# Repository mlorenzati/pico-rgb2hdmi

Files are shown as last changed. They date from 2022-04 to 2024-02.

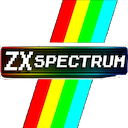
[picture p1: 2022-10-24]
tools/images/ZX-Spectrum.png

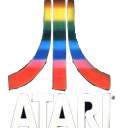
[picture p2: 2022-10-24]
tools/images/atari.png

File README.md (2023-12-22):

# pico-rgb2hdmi


Raspberry Pico as an RGB Scanner to HDMI Converter

## About the device
The device presents a simplistic approach of using a single generic purpose microcontroller to capture in real time RGB (CSYNC / HVSYNC) signals and to display it in an HDMI output without requiring FPGA chipsets of Single Boards computers with an HDMI diplay.
This system relies on the use of the PIO capabilities of the RP2040, to do dedicated processing of IO signals enabled with IRQ and DMA capabilites of the processor.

## Methodology
One processor is mostly dedicating to generate HDMI TMDS signals and the other to capture trigger captures and render on screen information among other functionalities.
PIO + DMA are used to dedicate the capture without requiring CPU intervention and to send the TMDS frames to the HDMI diplay.

# License - updated
The project full under the terms of the MIT license

# Collaboration
You are encouraged to build, develop and share, if you want to collaborate share PRs and github issues.

# Disclaimers
This solution (HW / FW /SW)  is provided as is without any express or implied warranties.

While every effort has been taken to ensure the solution will work as is, the authors & contributors assume no responsibility for errors or omissions, or for damages resulting from the use of the solution of the information contained herein.
There is no guarantee as to the suitability of said source code, executable scripts, circuits and other information, for any purpose whatsoever other than as a self-training aid.
I.E. If it blows your equipments, trashes your hard disc, wipes your backup, burns your building down or just plain don't work, IT ISN'T MY FAULT
I will not be held responsible for any damages or costs which might occur as a result of the usage of the beforementioned solution, USE IT AT YOUR OWN RISK

# Donations
You can allways collaborate to buy me coffees to focus on new cool features, this is my paypal.
[paypalme mlorenzati](https://www.paypal.com/paypalme/mlorenzati)

# PCB
You can build yourself the PCB out of the gerber in HW section, if you wan you can buy it in [pbcway pico-rgb2hdmi](https://www.pcbway.com/project/shareproject/pico_RGB_2_HDMI_3b12cb39.html)

# Setup
- Download the pico-sdk, pico-extras, and pico-playground repositories
- Define PICO_SDK_PATH in your ~/.bashrc• 
- Download the pico-sdk repository

# Security
Install sha3sum to hash the binary

## Mac
```
brew install md5sha1sum
```

## Local sha3sum usage for sha256
```
sha1sum <file>
echo -n "<device_salt><device_uid>" | sha1sum -b
```
## Tools
Tools were developed for sake of simplicity, focus is on firmware. 
It is required to install python3, pip and the following packages

```
pip install pyserial numpy pillow pyinstaller
```

## converting CSV captures from serial port to images
```
python3 csv2png.py image.csv
```
This generates as output image.png

## Using packtiles to generate include headers from images

./packtiles -s -f r1 char_c64_lineal.png font_c64.h

## Using packtiles to generate sprites
./packtiles -sdf rgab5515 -m  images/commodore.png cbm.h

## Running the python gui app
```
python .\rgb2hdmiGui.py
```

## Packaging the python app as a native app
```
pyinstaller -w -F rgb2hdmiGui.py
```

# Build
```
mkdir build
cd build
cmake .. -DCMAKE_BUILD_TYPE=Debug
```
Go to the specific folder and

`make -j4`

# Visual Studio Code integration
Install the extensions as explained in the  [Pico Getting started manual](https://datasheets.raspberrypi.org/pico/getting-started-with-pico.pdf)

Or just download [VScode](https://code.visualstudio.com/Download) and add the following extension

```
code --install-extension marus25.cortex-debug
code --install-extension ms-vscode.cmake-tools
code --install-extension ms-vscode.cpptools
```

# Debug
Install open ocd as explained in the [Pico Getting started manual section Installing OpenOCD](https://datasheets.raspberrypi.org/pico/getting-started-with-pico.pdf)

#Using Pico probe
On the same document check **Appendix A: Using Picoprobe**

Open deploy and run
```
openocd -f interface/picoprobe.cfg -f target/rp2040.cfg -c "program <specific elf file> verify reset exit"
```

# Read RP2040 to uf2
```
picotool save -a pico_rgb2hdmi_xyz.uf2
```

# Videos
pico RGB2HDMI Unified Firmware (https://youtu.be/40rTiWgZHxM)

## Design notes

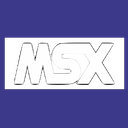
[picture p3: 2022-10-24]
tools/images/MSX.png

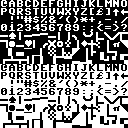
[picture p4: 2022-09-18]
tools/images/Font_64.png

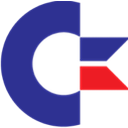
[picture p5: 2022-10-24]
tools/images/commodore.png

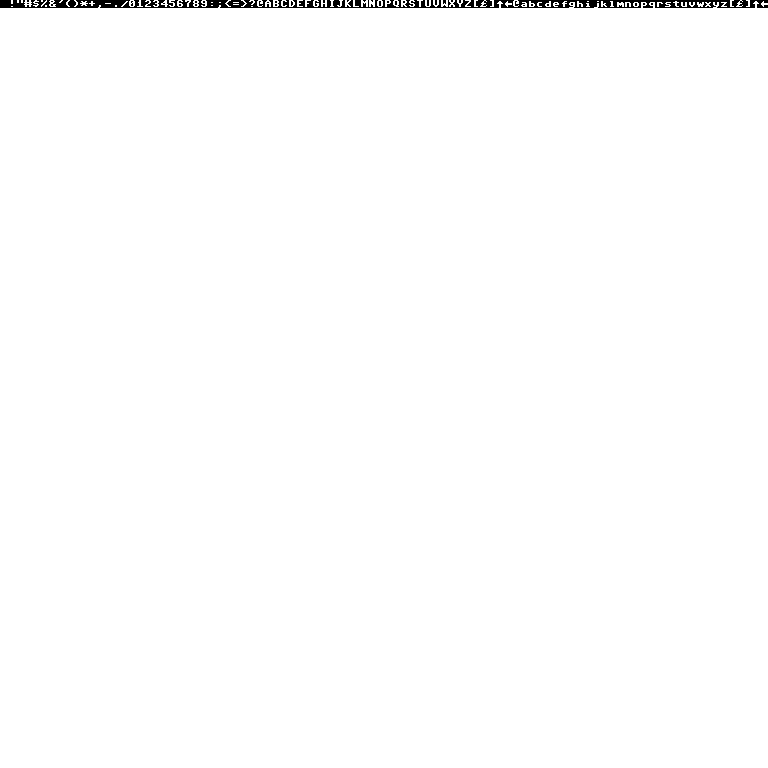
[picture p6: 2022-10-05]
tools/images/char_c64_lineal.png

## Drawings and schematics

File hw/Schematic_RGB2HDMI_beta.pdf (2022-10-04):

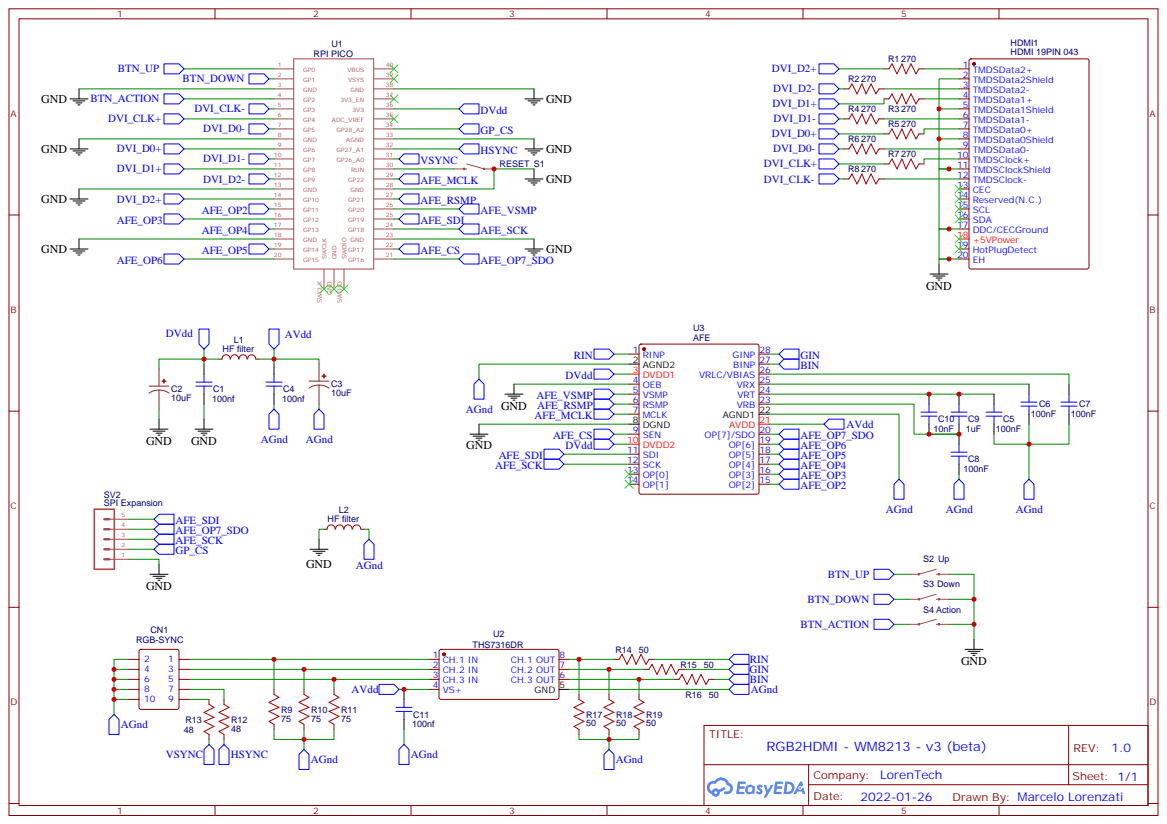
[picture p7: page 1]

Drawn By: Marcelo Lorenzati

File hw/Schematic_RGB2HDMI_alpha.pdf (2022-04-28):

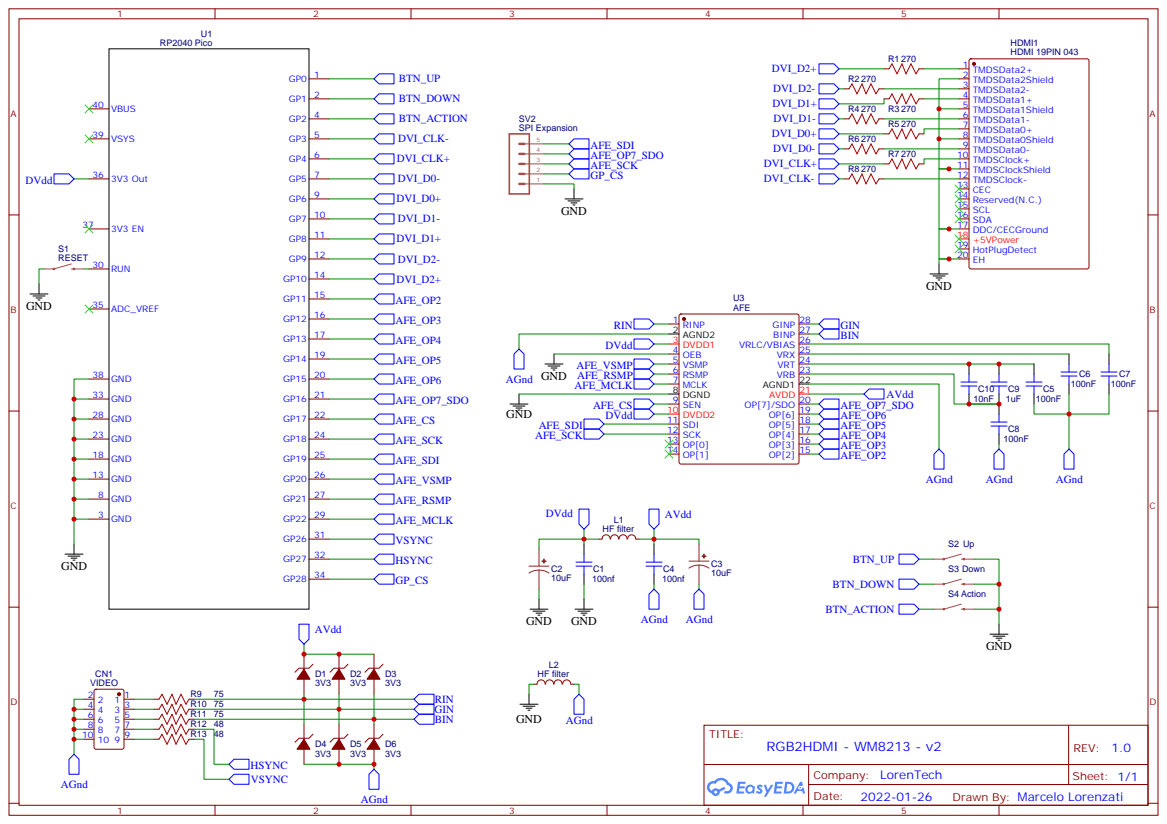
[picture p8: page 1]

Drawn By: Marcelo Lorenzati

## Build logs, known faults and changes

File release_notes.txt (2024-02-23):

Release Notes:
pico rgb2hdmi

An rpi pico microprocessed rgb 2 hdmi plus rgb 2 usb on the fly converter
-------------------------------------------------------------------------
Date: 2024/02/22
Version: 0.6.4
- Menu system for total control of gain, positive and negative offset, with RGB and unified options
-------------------------------------------------------------------------
Date: 2023/09/01
Version: 0.6.3
- Option to disable license validation on flash
-------------------------------------------------------------------------
Date: 2023/06/26
Version: 0.6.2
- Fixed integration test compilation/linker dependency to timer 
- Added all uf2 artifacts to CI Job zip file
-------------------------------------------------------------------------
Date: 2023/04/27
Version: 0.6.1
- Fix for unique horizontal timing, when doubling the value is adapted from stored value
- Added fine tune for pixel width, adds or substract in 1Khz steps the sample rate
-------------------------------------------------------------------------
Date: 2023/04/27
Version: 0.6.0
Major feature update: Unified Display mode (resolution and color depth for capture and display)
- Remove compile definitions for display mode
- Added logic to dinamically manage DVI display, stop, reconfigure and start
- Unified timings calculations
- Menu colors for 8 and 16 bits, when changing display mode, colors are defaulted
- DVI speed up with cached pre calculations!
- Callbacks are display mode dependant on runtime
- Improved AFE configs separating const config from variable configs

-------------------------------------------------------------------------
Date: 2023/04/22
Version: 0.5.2
- Scan lines support with menu and settings when using vertical line repeat
- Display config 4 has a SOG (sync on green) setup
- Fixed gain error that limited to 63
-------------------------------------------------------------------------
Date: 2023/04/21
Version: 0.5.1
- Fixed GUI/Graphics test due to latest changes
- Fixed storage dependency for multicore
-------------------------------------------------------------------------
Date: 2023/04/14
Version: 0.5.0
Major feature update: added settings persistence and menu integration
- Save settings and revert to factory
- Maintains license, and cover upgrade process from basic settings
- Menu system updated for 4 displays options
- gain, offset, alignment, pix width, auto shutdown and gui palette can be saved

-------------------------------------------------------------------------
Date: 2023/04/12
Version: 0.4.5
- Fix for capture changes (like pixel width) that affected the pio and made it stall

-------------------------------------------------------------------------
Date: 2023/02/28
Version: 0.4.4
- Improvement over capture: trigger fast front porch dma, then prepare capture dma (dough!)
- keyboard wake: on key pressed the shutdown screen timer is refreshen when there is no video, wakes the screen too

-------------------------------------------------------------------------
Date: 2023/02/28
Version: 0.4.3
- Implemented DVI start / stop
- Implemented configurable HDMI display auto shutdown on no signal
- Auto starts DVI on signal
- Added a level of submenus with config and display groups

-------------------------------------------------------------------------
Date: 2023/02/25
Version: 0.4.2
- Added missing enable USB button on diagnostic for Command line on serial

-------------------------------------------------------------------------
Date: 2022/12/08
Version: 0.4.1
- Support and menu connection of gain and offset control
- Sampling rate removed from config, is calculated based on video settings

-------------------------------------------------------------------------
Date: 2022/12/08
Version: 0.4.0
- Included menu support based on an event based GUI
    - 8 object in left button groups
    - 8 objects in main view
    - show hide overlay with buttons
    - mapping of keys with event types
    - navigation on navigable object improvement
    - Added about, palette, save & reboot, diagnostics and alignment menues
        - Palette menu changes active colors
    - Factory option
    - Gain & offset, automatic option
    - license show and start image
    - alignment control connection to ui with pixel width
    - diagnostics shows sync type
- group unsubscribe improvement
- group loop callback tool with break condition and count of results
- focus change fix
- color api for RGB in different modes
- event fix to support multiple subscribers and destination with diferent actions
- event non propagation fix
- scanner provides number of hsync lines
- scanner sync type detection and show on screen
- scanner and afe can restart capture
-------------------------------------------------------------------------
Date: 2022/11/13
Version: 0.3.4
- Initial CSYNC support

-------------------------------------------------------------------------
Date: 2022/10/14
Version: 0.3.3
- Storage fix: 
  On new devices without license, the device went to watchdog reset
  
-------------------------------------------------------------------------
Date: 2022/10/04
Version: 0.3.2
- Completed UI Python App with autodetect, move screen buttons, capture
  and device identification
- GUI lib(not integrated to device)
  buttons, sliders, labels, spinbox and groups (shared and not shared)
  event management and propagation
  focus management
- Tiles and fonts tool
- Beta HW consolidation support
- Security: license validation fixes
- Storage: Usage of storage with a subsequent reboot
- Commands: reboot
- Added purchase mode fw with VYSNC/HSYNC info at the bottom of the screen

-------------------------------------------------------------------------
Date: 2022/08/09
Version: 0.3.1
- Image capture supports, 8 and 16 bits modes
- Added mode command to report current resolution and color density

-------------------------------------------------------------------------
Date: 2022/08/08
Version: 0.3.0
- Completed 640x240 8 bits RGB332 mode and 320x240 16 bits RGB 565 mode
on HMDI rendering and ADC capture compressing

-------------------------------------------------------------------------
Date: 2022/06/17
Version: 0.2.1
- Initial release of the rgb2hdmi
    - 320x240 @ 16 bits per pixel
    - Basic buttons functionality usage (move screen), supports on key up
      key down, key timeout
    - Secure key unique identification
    - Video overlay
    - Command line interface through USB (must be enabled from buttons)
        -RGB to USB Image capture
        -move image
    - Graphics drawing capabilities, initial menu system

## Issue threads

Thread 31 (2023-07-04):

Undefined reference during build

charlysan, 2023-07-04:
When trying to link `integrationTest.elf` I get an `undefined reference to video_overlay_scanline_prepare` error. Full log dump below:

```
/home/dev/build # cmake .. -DCMAKE_BUILD_TYPE=Debug && make
PICO_SDK_PATH is /usr/share/pico_sdk
PICO platform is rp2040.
Build type is Debug
Using regular optimized debug build (set PICO_DEOPTIMIZED_DEBUG=1 to de-optimize)
PICO target board is pico.
Using board configuration from /usr/share/pico_sdk/src/boards/include/boards/pico.h
TinyUSB available at /usr/share/pico_sdk/lib/tinyusb/src/portable/raspberrypi/rp2040; enabling build support for USB.
Compiling TinyUSB with CFG_TUSB_DEBUG=1
BTstack available at /usr/share/pico_sdk/lib/btstack
cyw43-driver available at /usr/share/pico_sdk/lib/cyw43-driver
Pico W Bluetooth build support available.
lwIP available at /usr/share/pico_sdk/lib/lwip
mbedtls available at /usr/share/pico_sdk/lib/mbedtls
-- Configuring done
-- Generating done
-- Build files have been written to: /home/dev/build
Scanning dependencies of target bs2_default
[  0%] Built target bs2_default
[  0%] Performing build step for 'PioasmBuild'
[100%] Built target pioasm
[  0%] No install step for 'PioasmBuild'
[  1%] Completed 'PioasmBuild'
[  1%] Built target PioasmBuild
[  1%] Built target rgbScan_wm8213Afe_pio_h
[  2%] Built target bs2_default_padded_checksummed_asm
Scanning dependencies of target rgbScanTest
Consolidate compiler generated dependencies of target rgbScanTest
[ 11%] Built target rgbScanTest
[ 11%] Built target libdvi_tmds_encode_1bpp_pio_h
[ 11%] Built target libdvi_dvi_serialiser_pio_h
Scanning dependencies of target hdmiTest
Consolidate compiler generated dependencies of target hdmiTest
[ 20%] Built target hdmiTest
Scanning dependencies of target afeTest
Consolidate compiler generated dependencies of target afeTest
[ 29%] Built target afeTest
Scanning dependencies of target keyboardTest
Consolidate compiler generated dependencies of target keyboardTest
[ 37%] Built target keyboardTest
Scanning dependencies of target storageTest
Consolidate compiler generated dependencies of target storageTest
[ 45%] Built target storageTest
[ 45%] Performing build step for 'ELF2UF2Build'
[100%] Built target elf2uf2
[ 45%] No install step for 'ELF2UF2Build'
[ 45%] Completed 'ELF2UF2Build'
[ 45%] Built target ELF2UF2Build
Scanning dependencies of target securityTest
Consolidate compiler generated dependencies of target securityTest
[ 53%] Built target securityTest
Scanning dependencies of target graphicsTest
Consolidate compiler generated dependencies of target graphicsTest
[ 62%] Built target graphicsTest
Scanning dependencies of target spriteTest
Consolidate compiler generated dependencies of target spriteTest
[ 72%] Built target spriteTest
Scanning dependencies of target guiTest
Consolidate compiler generated dependencies of target guiTest
[ 81%] Built target guiTest
Scanning dependencies of target integrationTest
Consolidate compiler generated dependencies of target integrationTest
[ 81%] Linking CXX executable integrationTest.elf
/usr/lib/gcc/arm-none-eabi/12.2.0/../../../../arm-none-eabi/bin/ld: CMakeFiles/integrationTest.dir/integrationTest.c.obj: in function `scanLineTriggered_8':
/home/dev/test/integrationTest/integrationTest.c:117: undefined reference to `video_overlay_scanline_prepare'
/usr/lib/gcc/arm-none-eabi/12.2.0/../../../../arm-none-eabi/bin/ld: CMakeFiles/integrationTest.dir/integrationTest.c.obj: in function `scanLineTriggered_16':
/home/dev/test/integrationTest/integrationTest.c:128: undefined reference to `video_overlay_scanline_prepare'
collect2: error: ld returned 1 exit status
make[2]: *** [test/integrationTest/CMakeFiles/integrationTest.dir/build.make:1638: test/integrationTest/integrationTest.elf] Error 1
make[1]: *** [CMakeFiles/Makefile2:2676: test/integrationTest/CMakeFiles/integrationTest.dir/all] Error 2
make: *** [Makefile:91: all] Error 2
```

I've checked the imports and `CMakeLists.txt` file, but everything looks OK.

Any clues on what I might be missing here?

Thanks!

mlorenzati, 2023-07-07:
Hi, long week, I did a clean CMAKE and make of the solution without issues.
from the root project I just
```
mkdir build && cd build && cmake .. &
make -j4
```
This compiled all without issues, just remember to set **PICO_SDK_PATH**\

Attached [logs.txt](https://github.com/mlorenzati/pico-rgb2hdmi/files/11986247/logs.txt)

Additionally setting the vscode environment it automatically set ups and builds everything

mlorenzati, 2023-07-07:
**video_overlay_scanline_prepare** is an inline method part of the overlay.h used only in the integration test.
CMakelist of integration test add overlay as a submodule, so it should work

charlysan, 2023-07-08:
Thanks for double checking that. It looks like I had some issue in my `build` directory. After I removed the folder and re builded everything from scratch again, I got no errors.

I'm closing this issue.

Closed 2023-07-08.

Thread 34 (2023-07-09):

MDA/Hercules Support

charlysan, 2023-07-09:
## Introduction

The purpose of this issue is to start a discussion about MDA/Hercules implementation.

## Requirements & specs

### Features and DB9 Pinout

Feature / DB9 Pin Number | IBM MDA | Hercules Graphics Card (HGC)
-- | -- | --
Text Mode | 80x25 characters (720x350 pixels) | 80x25 characters (720x350 pixels)
Graphics Mode | None | 720x348 pixels
Vertical Sync Frequency | 50 Hz | 50 Hz
Horizontal Sync Frequency | ~18.432 kHz | ~18.432 kHz
Signal Type | TTL Digital | TTL Digital
Pin 1 | Ground | Ground
Pin 2 | Ground | Ground
Pin 3 | Not connected | Not connected
Pin 4 | Not connected | Not connected
Pin 5 | Not connected | Not connected
Pin 6 | Intensity | Intensity
Pin 7 | Video | Video
Pin 8 | Horizontal Sync | Horizontal Sync
Pin 9 | Vertical Sync | Vertical Sync

<br class="Apple-interchange-newline">

### Intensity for Graphics Mode

Video | Intensity | Resulting 'colour'
-- | -- | --
0 | 0 | Black
0 | 1 | Dim
1 | 0 | Normal
1 | 1 | Bright

## Implementation

### Hardware

We could connect `Video` to `Rin`, and `Intensity` to `Gin` for example.

### Software

TBD

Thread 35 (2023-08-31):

CSYNC only will it work

shift838, 2023-08-31:
I have an old computer that has CSYNC, Red, Green, Blue and ground.

Will this work for a system that only has a CSYNC line?

mlorenzati, 2023-08-31:
Hi @shift838, short answer is yes, since the code is prepared to use HSYNC line to manage CSYNC when HSYNC is grounded.
The double click is that not all CSYNCs are the same, example wise I know it works with SEGA and AMIGA CSYNC, but Sinclair + uses inverter polarity for vertical inside the CSYNC.
The next step is to test it, and if it does not work we need to add a config option to invert VSYNC polarity triggering inside CSYNC.

shift838, 2023-09-01:
Is the latest gerbers the Beta3?

mlorenzati, 2023-09-02:
Latest PCB is on PCB Way
https://www.pcbway.com/project/shareproject/pico_RGB_2_HDMI_3b12cb39.html

I did not check the gerbers on github, that was other collaborator work

El vie, 1 sept 2023 a la(s) 18:37, shift838 ***@***.***)
escribió:

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

shift838, 2023-09-02:
Also it seems the wm8213 IC it is designed for is obsolete and so is the alternate WM8199.  Is there another IC that can be used on this board to replace it?

mlorenzati, 2023-09-02:
wm8199 is not yet a replacement there are some fundamental changes that
renders it invalid.
We need another AFE family

El sáb, 2 sept 2023, 0:19, shift838 ***@***.***> escribió:

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

mwedmark, 2023-10-31:
AD9826 seem to be very similar, still available pretty cheap but also "on the way out". Maybe worth trying out?

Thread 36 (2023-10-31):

Amiga DB23 To Beta3 Pin Header Mapping

mrgo0se, 2023-10-31:
Hi,

Is there an existing schematic/diagram anywhere showing the exact pin mapping between Amiga DB23 and the Beta3 PCB pin header signals, including appropriate grounds?

I am fairly confident that I have this wired correctly and get display/diagnostic menu on screen but only alternating black screen and garbled video signal output.

If you could post a mapping in the repo for wiring using CSYNC and alternatively HSYNC/VSYNC via the DB23 that would be great.

I'm also using the WM8214 AFE rather than the WM8213 if that makes any difference?

Cheers.

mlorenzati, 2023-10-31:
The picoRGB2HDMI is generalistic to use any retrocomputer with RGB or RGBi output (prior converting signal) that's why I do not add a circuit to the DB23 since its just pin to pin connection.
The board can use either CSYNC or HSYNC+VSYNC.
For the first one, leave board HSYNC Grounded and connect Amiga CSYNC to the board HSYNC.
Check here the pinout of Amiga https://inanis.net/amiga-500-to-amiga-1084-rgb-cable/
You can use one or the three ground amiga pin 16,17,18

Regarding WM8214 is compatible with WM8213 but faster, I saw that it might have a slightless timing difference that could shift colors. For sake of simplicity I'm about to push in this days a feature to manage gain/offset per RGB color.

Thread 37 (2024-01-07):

Firmware

thbreidenbach, 2024-01-07:
Hey, could you elaborate on the firmware release? The Binaries include several test u2f but I'm asking myself which is the exact firmware.
I just finished my build an hopefully it'll work.

mlorenzati, 2024-01-07:
Sure, there package has different test for the submodules, the one you want for RGB2HDMI is the integrationtest.uf2
Please start validating HDMI works (check the Resistor array is are not tied to each other or to ground), then check AFE.
If youc can validate with microscope the pins on the AFE and clean througfully solder flux since it affects the capture.

thbreidenbach, 2024-01-07:
Great, Thank! I upladed the integrationtest firmware and can successfully see the menu. Colors are washed out greatly which might be an issue with the used WM8214. Will start working on a db23 adapter and test on!!
Maybe you could collect the different sources of information (PCBWay, Google, etc.) here? I will assemble information for a1k.org and will give some assembled boards to testers there. Is there something to keep in mind regarding the WM8214 whilest troubleshooting?

mlorenzati, 2024-01-08:
I do need to complete what I started in https://github.com/mlorenzati/pico-rgb2hdmi/tree/gain_offset_options to allow offset and gain per RGB to manage the color differences due to timing between WM8213 and WM8214.
Also could be possible to tweak the timing on the pio capture program but that would be an overkill IMO.
If colors are shifted that's the wm8412 timing, if washed is more related to flux messing with an unwanted rc profile

thbreidenbach, 2024-01-11:
Hi, I get really bad sync and colors are way off which will be an issue of the wm8214. At first the picture is extremely dim ´. With gain and offset this can be partially solved but blue seems to be mostly missing. Would it be possible to output a dedicated test image on the host computer and let the pi calculate offset and gain per rgb?

mlorenzati, 2024-01-11:
Bad sync can be multiple things, please check videos on yt about how it looks like as for today, since video has some glitches that has to be managed on firmware but not extreme.
To validate you have a clean WM8214, (as I said clean with iso and toothbrush and clean with hot air on 200-240 degrees.

Finally, set video capture on 320x240 to  see how it looks, if better you have pending dirt.
I still need to complete manual per RGB gain and offset, no time to complete it yet.

ottifant011, 2024-01-30:
I have built myself a Pico RGB2HDMI.
How can I programme it under windows? Is there a manual for beginners?

thbreidenbach, 2024-01-30:
Usually one just connects the RPi Pico to the windows computer and drags the fw file in the newly added drive (which represents the pi) which firmware you need can be seen in this thread. (integrationtest.uf2)
Which Chip do you use? WM8213 or WM8214?

ottifant011, 2024-01-30:
hm i have already done that but nothing is happening, no image output no flashing led nothing.
I only got the WM8214

ottifant011, 2024-01-30:
if i de-energise the pico it seems to be empty again u2f file no longer there

ottifant011, 2024-01-30:
> @ottifant011, können Sie zunächst einmal ausprobieren `hdmiTest.uf2`. Das sollte einiges über den HDMI-Anschluss senden. Und denken Sie daran, dass sich der Pico im Massenspeichermodus befinden MUSS, um eine UF2-Datei darauf übertragen zu können. Halten Sie dazu die BOOTSEL-Taste gedrückt und schließen Sie dann den Pico an. Lassen Sie dann die BOOTSEL-Taste los.

das hab ich schon probiert das geht leider auch nichts bzw. kein HDMI Signal

ottifant011, 2024-01-30:
what i don't understand it is immediately recognised as a drive without me having to press a button

thbreidenbach, 2024-01-30:
Why wouldn’t it? That’s how it’s built.

mlorenzati, 2024-01-30:
@ottifant011, to burn the firmware into the device
- press RESET
- press BOOT
- release RESET
That should show the pen drive option on the computer

Start with the simple HDMI demo, test it in monitors with DVI back compatibility, TVs is more likely not to work with that firm.

HDMI support has to be integrated from what I built in https://github.com/mlorenzati/PicoDVI

ottifant011, 2024-01-31:
i just can't get a picture output, a monitor says outside the working area

charlysan, 2024-01-31:
@ottifant011, have you tried using a different monitor? My monitor experiences issues at certain resolutions, however, `hdmiTest.uf2` has always worked. What about your Pico? Have you checked to ensure it's working well?

charlysan, 2024-01-31:
I've just checked using `hdmiTest.uf2` from `pico-rgb2hdmi-0.6.3.zip` and it works as expected. I followed the [instructions](https://github.com/mlorenzati/pico-rgb2hdmi/issues/37#issuecomment-1917983604) from Marcelo.

ottifant011, 2024-01-31:
tomorrow i will build a new one piece by piece, for HDMI test picture you don't need an input circuit with ic's.
I'm building the Beta3 but that shouldn't matter, maybe the chinese have delivered with it.
Do all HDMI sockets have the same pinout? not that's where the fault lies

ottifant011, 2024-02-01:
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

I did it exactly the same way and no test image appears even when rebuilding

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

charlysan, 2024-02-01:
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

@ottifant011, I recommend opening a new issue titled 'No HDMI Output' for a detailed discussion on this problem, since the current thread is specifically for clarifying aspects of the firmware release.

And considering that the main question in this discussion has been resolved, I am now closing this issue.

cc: @mlorenzati

Closed 2024-02-01.

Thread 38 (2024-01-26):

WM8231? Other ICs?

King-Icewind, 2024-01-26:
Hello,

As you know, the WM2813 is now obsolete. What are your thoughts on using the WM8231? It is an active part for now.

Any other possible ICs to use? Could an STM32F11 be used in lieu of an AFE?

thanks!

mlorenzati, 2024-01-26:
On the first question, I have to see in detail but on a high level view,
there are significant differences. Just see WM8199, is pin compatible and
it has hw and peripherals differences.
I'm analysing the LM98714 which is 45Msps 3 channels afe and most
importantly cost effective.

Regarding the MCU, is heavy using the PIO interface that releases a lot of
cpu usage and has great interconnection to DMA/IRQ.

El vie, 26 ene 2024 a la(s) 7:24 p.m., Keys of Kings (
***@***.***) escribió:

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

King-Icewind, 2024-01-26:
> On the first question, I have to see in detail but on a high level view, there are significant differences. Just see WM8199, is pin compatible and it has hw and peripherals differences. I'm analysing the LM98714 which is 45Msps 3 channels afe and most importantly cost effective. Regarding the MCU, is heavy using the PIO interface that releases a lot of cpu usage and has great interconnection to DMA/IRQ. El vie, 26 ene 2024 a la(s) 7:24 p.m., Keys of Kings ( ***@***.***) escribió:
> […](#)
> Hello, As you know, the WM2813 is now obsolete. What are your thoughts on using the WM8231? It is an active part for now. Any other possible ICs to use? Could an STM32F11 be used in lieu of an AFE? thanks! — Reply to this email directly, view it on GitHub <#38>, or unsubscribe <https://github.com/notifications/unsubscribe-auth/ABJGQOZWGVMSHFNZOOKS4Z3YQQULNAVCNFSM6AAAAABCMZW772VHI2DSMVQWIX3LMV43ASLTON2WKOZSGEYDEOJYHA2TKOA> . You are receiving this because you are subscribed to this thread.Message ID: ***@***.***>

Thank you for the reply. Unfortunately, the WM8199 is end of life. I’m not worried about pin compatibility as my application is custom. Interested in the LM98714. Thanks for all the great work.

mlorenzati, 2024-02-25:
I'm placing my last bits into this version (HDMI + audio + stabilization) and I'll move to the R&D on LM98714, stay tuned!

mlorenzati, 2024-04-04:
Yes, it works perfectly and has higher sampling rate, if the colors get shifted due to timing differences, the latest version supports gain/offset setup per individual RGB

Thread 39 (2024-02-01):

No HDMI output

ottifant011, 2024-02-01:
@charlysan sorry for spamming the firmware topic, I thought I did something wrong when programming.
So I have a fully built card and a card half built and just get no picture output, it is not yet recognized that an HDMI is active.
I have the firmware HDMItest on it

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

charlysan, 2024-02-01:
No worries @ottifant011. I would do the following tests:

1. Check with different HDMI cable
2. Check with different monitor
3. Visually check HDMI connector (pins soldered to pcb pads)

ottifant011, 2024-02-01:
Thanks, tried several HDMI cables, only tested 2 monitors so far and used firmware from github. Hdmi socket optically checked no short circuits visible also measured the resistors to see if there are any short circuits.
are there HDMI sockets with different pinouts? i had some lying around and used these too.
What kind of monitors do you have? could you look in your company to see if you can find one?

mlorenzati, 2024-02-25:
If it is a monitor, it will work, on HDMI monitor is not that easy.
I have a Samsung S20B300B, a DELL U2415, an HP 20 inches I cannot see the model and a chinese TV/monitor.
If you want to test HDMI, compile and use the HDMI example (with audio) on https://github.com/mlorenzati/PicoDVI
That works on any TV & monitor since is a more broadly available standard.
Again, I would check HDMI pins are not shortcircuited on resistor pack or in HDMI connector

JmanNZ, 2024-07-11:
Could somebody please provide the complete functioning-built firmware. I have test ones provided here and my own complied test ones.

Thank you

mlorenzati, 2024-07-11:
> Could somebody please provide the complete functioning-built firmware. I have test ones provided here and my own complied test ones.
>
> Thank you

it´s on the [Releases Page](https://github.com/mlorenzati/pico-rgb2hdmi/releases/tag/0.6.4)

The zip has multiple tests, the one that integrates all is the integrationTest

JmanNZ, 2024-07-11:
> it´s on the [Releases Page](https://github.com/mlorenzati/pico-rgb2hdmi/releases/tag/0.6.4)
>
> The zip has multiple tests, the one that integrates all is the integrationTest

Thank you

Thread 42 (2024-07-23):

afe test

JmanNZ, 2024-07-23:
Hi.
What should the response be when using the afe test.
I have a flashing LED when using the afe test.

Thank you

JmanNZ, 2024-07-24:
I see its sending the below from the usb com port.
Is the below normal ?

RED     GREEN   BLUE
3.300000        3.300000        3.300000
3.300000        3.300000        3.300000
3.300000        3.300000        3.300000
3.300000        3.300000        3.300000
3.300000        3.300000        3.300000
3.300000        3.300000        3.300000
3.300000        3.300000        3.300000
3.300000        3.300000        3.300000
3.300000        3.300000        3.300000
3.300000        3.300000        3.300000
3.300000        3.300000        3.300000
3.300000        3.300000        3.300000
3.300000        3.300000        3.300000
3.300000        3.300000        3.300000
3.300000        3.300000        3.300000
3.300000        3.300000        3.300000
3.300000        3.300000        3.300000
3.300000        3.300000        3.300000
3.300000        3.300000        3.300000
3.300000        3.300000        3.300000
3.300000        3.300000        3.300000
3.300000        3.300000        3.300000
3.300000        3.300000        3.300000
3.300000        3.300000        3.300000
3.300000        3.300000        3.300000
3.300000        3.300000        3.300000
3.300000        3.300000        3.300000
3.300000        3.300000        3.300000
3.300000        3.300000        3.300000
3.300000        3.300000        3.300000
3.300000        3.300000        3.300000
3.300000        3.300000        3.300000

RED     GREEN   BLUE
0.319355        0.576190        0.638710
0.000000        0.052381        0.000000
0.000000        0.000000        0.000000
0.000000        0.000000        0.000000
0.000000        0.000000        0.000000
0.000000        0.000000        0.000000
0.000000        0.000000        0.000000
0.000000        0.000000        0.000000
0.000000        0.000000        0.000000
0.000000        1.047619        0.958065
0.000000        0.995238        0.851613
0.000000        0.000000        0.000000
0.000000        0.000000        0.000000
0.000000        0.000000        0.000000
0.000000        0.000000        0.000000
0.000000        0.000000        0.000000
0.000000        0.000000        0.000000
0.000000        0.000000        0.000000
0.000000        0.000000        0.000000
0.000000        0.000000        0.000000
0.000000        0.000000        0.000000
0.000000        0.000000        0.000000
0.000000        0.000000        0.000000
0.000000        0.000000        0.000000
0.000000        0.000000        0.000000
0.000000        0.000000        0.000000
0.000000        0.000000        0.000000
0.000000        0.000000        0.000000
0.000000        0.000000        0.000000
0.000000        0.000000        0.000000
0.000000        0.000000        0.000000

Thanks

mlorenzati, 2024-07-24:
Afe test is a simple validation placing each line with a constant value from 0 to 1volt constant to see what is being reported.
YOu can directly place integrationTest binary to test all
if there are issues with afe either shows in the status dialog afe error (AFE chip issue) or works with visible artifacts (AFE works but is dirty or with circuit issues)

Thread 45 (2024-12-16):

[FEATURE REQUEST] Pico2 or OC to  extended capabilities

methanoid, 2024-12-16:
In one of the YT videos it was mentioned about using a carrier board to allow future Picos to be used.

Would that offer new features (like the requested Web Interface) or better still, increased resolutions.

I am concerned that for an Amiga which in PAL territory uses 320x256 this is 320x240 and hence would chop off some part of the screen....    Would overclocking allow 320x256 or is that limited some other way? Or could 320x256 8 bit colour be offered as 8 bit allows 256 colours?

(unrelated)...

mlorenzati, 2024-12-16:
2024 was a year full of activities and I could not make progress on the converter but I bought to start a new model with pico 2 an a TI AFE of 45Msps (LM98714), you can help if you like.
The idea is leave 1 core go run tmds encoding and dedicate others to capture or windows mgmt.
It has more memory and  cores to do the job

mlorenzati, 2024-12-16:
1. Yes, mostly TMDS encoding requirements, capture is mostly done in DMA and state machines.
2. Yes, due to memory limitations, if you want 320 pixels wide you need 8 bits color compression. The 240 lines instead of 256 is due to choosing 640x480 video mode, hence 240 lines x 2
3. I did not make the 3d model, was a contributor design (DefLepard aka C64iSTANBUL) you can ask him, anyways can be easily modified

c64istanbul, 2024-12-20:
Hello,
I am c64istanbul, I am not DefLepard.
It is a nice case but I did not designed it.
Please contact DefLepard.
Thank you.

c64istanbul, 2024-12-20:
Hello,
I am c64istanbul, I am not DefLepard. DefLepard is a different person.
It is a nice case but I did not design it.
Please contact DefLepard.
Thank you.

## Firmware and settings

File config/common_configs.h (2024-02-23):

#ifndef _COMMON_CONFIGS_H
#define _COMMON_CONFIGS_H

//Keyboard
#ifdef _KEYBOARD_H
    #define KEYBOARD_N_PINS          3
    #define KEYBOARD_PIN_UP          0
    #define KEYBOARD_PIN_DOWN        1
    #define KEYBOARD_PIN_ACTION      2
    #define KEYBOARD_REFRESH_RATE_MS 25
    #define KEYBOARD_REPEAT_RATE_MS  2000
#endif

#ifdef _MENU_H
    #define MENU_VIDEO_OVERLAY_WIDTH   -200
    #define MENU_VIDEO_OVERLAY_HEIGHT  -104
#endif

//SYNC edge triggered Pins
#ifdef _RGB_SCANNER_H
    #define RGB_SCAN_VSYNC_PIN  26
    #define RGB_SCAN_HSYNC_PIN  27
#endif

//VIDEO Timing
#define V_FRONT_PORCH            42
#define V_BACK_PORCH             54
#define REFRESH_RATE             50
#define HSYNC_FRONT_PORCH        100
#define HSYNC_BACK_PORCH         50
#define DEFAULT_SYMBOLS_PER_WORD 1

//AFE (Analog Front End) Specific Config
#ifdef _WM8213_AFE_H
    //AFE SPI Pins
    #define AFE_SDO  16
    #define AFE_CS   17
    #define AFE_SCK  18
    #define AFE_SDI  19

    //AFE Paralel port pins
    #define AFE_OP        11 //Takes 6 pins starting from the beforementioned number
    #define AFE_VSMP    20 //Video Sample timing pulse
    #define AFE_RSMP    21 //Reset sample timing pulse
    #define AFE_MCLK    22 //Master ADC Clock

    //VSMP ___________________|‾|___________________________|‾|____________
    //RSMP ____|‾|___________________________|‾|___________________________
    //MCLK ____|‾‾‾‾|____|‾‾‾‾|____|‾‾‾‾|____|‾‾‾‾|____|‾‾‾‾|____|‾‾‾‾|____
    //OP   ===>.<===R===>.<===G===>.<===B===>.<===R===>.<===G===>.<===B===>

    #define AFE_PGA_GAIN_RGB          61
    #define AFE_PGA_GAIN_RGB_SOG      75
    #define AFE_RLC_DAC_NEG           1
	#define AFE_OFFSET_DAC            0
	#define AFE_OFFSET_DAC_SOG_RED    230
    #define AFE_OFFSET_DAC_SOG_GREEN  230/6
	#define AFE_OFFSET_DAC_SOG_BLUE   230

    static const wm8213_afe_config_t afec_cfg = {
        .spi = spi0,
        .baudrate = 1 * MHZ,
        .pins_spi = {AFE_SCK, AFE_SDI, AFE_SDO, AFE_CS},
        .setups = {
            .setup1 = {
                .enable = 1,
                .cds= 0,
                .mono = 0,
                .two_chan = 0,
                .pgafs = 3,
                .mode_4_legacy = 0,
                .legacy = 0
            },
            .setup2 = {
                .opp_form = 1,
                .invop = 0,
                .opd = 0,
                .low_refs = 0,
                .rlc_dac_rng = 0,
                .del = 0
            },
            .setup3 = {
                .rlc_dac = AFE_RLC_DAC_NEG,
                .cds_ref = 0,
                .chan = 0
            },
            .setup4 = {
                .line_by_line = 0,
                .acyc =  0,
                .intm = 0
            },
            .setup5 = {
                .red_pd = 0,
                .green_pd = 0,
                .blue_pd = 0,
                .adc_pd = 0,
                .vrlc_dac_pd = 0,
                .vrx_pd = 0
            },
            .setup6 = {
                .vsm_pdet = 0,
                .vdel = 0,
                .posn_neg = 0,
                .rlc_en = 0,
                .clamp_ctrl = 0
            },
            // .offset_dac = {
            //     .red = AFE_OFFSET_DAC,
			// 	.green = AFE_OFFSET_DAC,         // Common config
			// 	//.green = (1 * AFE_OFFSET_DAC) / 5, // SOG config
            //     .blue = AFE_OFFSET_DAC
            // },
            // .pga_gain = {
            //     .red = {
            //         .lsb =  AFE_PGA_GAIN_RGB & 0x01,
            //         .msb = (AFE_PGA_GAIN_RGB >> 1) & 0xFF
            //     },
            //     .green = {
            //         .lsb =  AFE_PGA_GAIN_RGB & 0x01,
            //         .msb = (AFE_PGA_GAIN_RGB >> 1) & 0xFF
            //     },
            //     .blue = {
            //         .lsb =  AFE_PGA_GAIN_RGB & 0x01,
            //         .msb = (AFE_PGA_GAIN_RGB >> 1) & 0xFF
            //     }
            // }
        },
        .verify_retries = 3,
        .pio = pio1,
        .sm_afe = 0,
        .pin_base_afe_op = AFE_OP,
        .pin_base_afe_ctrl = AFE_VSMP
    };
#endif

//DVI Specific configs
#ifdef _DVI_SERIALISER_H
    //DVI Config
    #define DVI_DEFAULT_SERIAL_CONFIG    picodvi_dvi_cfg
    #define DVI_DEFAULT_PIO_INST         pio0

    static const struct dvi_serialiser_cfg picodvi_dvi_cfg = {
        .pio = pio0,
        .sm_tmds = {0, 1, 2},
        .pins_tmds = {5, 7, 9},
        .pins_clk = 3,
        .invert_diffpairs = true,
        .symbols_per_word = false
    };
#endif

// Colors 16bits            0brrrrrggggggbbbbb
#define color_16_black      0b0000000000000000
#define color_16_dark_gray  0b0001100011100011
#define color_16_mid_gray   0b1010010100010000
#define color_16_light_gray 0b1100011000011000
#define color_16_white      0b1111111111111111
#define color_16_red        0b1111100000000000
#define color_16_green      0b0000011111100000
#define color_16_blue       0b0000000000011111
// Colors 8 bits            0brrrgggbb
#define color_8_black       0b00000000
#define color_8_dark_gray   0b01001001
#define color_8_mid_gray    0b10110110
#define color_8_light_gray  0b11011011
#define color_8_white       0b11111111
#define color_8_red         0b11100000
#define color_8_green       0b00011100
#define color_8_blue        0b00000011

#define DEFAULT_MENU_COLORS_16 { color_16_dark_gray, color_16_light_gray, color_16_white, color_16_black, color_16_mid_gray, color_16_green}
#define DEFAULT_MENU_COLORS_8  { color_8_dark_gray, color_8_light_gray, color_8_white, color_8_black, color_8_mid_gray, color_8_green}


#if DEFAULT_SYMBOLS_PER_WORD == 2
    #define DEFAULT_MENU_COLORS DEFAULT_MENU_COLORS_16
#else
    #define DEFAULT_MENU_COLORS DEFAULT_MENU_COLORS_8
#endif

// Global settings 
#ifdef _SETTINGS_H
    // Factory Settings
    #define GET_FACTORY_SETTINGS() { \
            .security_key = { 0x0, 0x1, 0x2, 0x3, 0x4, 0x5, 0x6, 0x7, 0x8, 0x9, 0xA, 0xB, 0xC, 0xD, 0xE, 0xF, 0x10, 0x11, 0x12, 0x13 },\
            .menu_colors = DEFAULT_MENU_COLORS, \
            .flags.auto_shut_down = 1, \
            .flags.default_display = 0, \
            .flags.scan_line = 0, \
            .flags.symbols_per_word = DEFAULT_SYMBOLS_PER_WORD == 2, \
            .displays = {{ \
                    .gain = { .red = AFE_PGA_GAIN_RGB, .green = AFE_PGA_GAIN_RGB, .blue = AFE_PGA_GAIN_RGB}, \
                    .offset = { .red = AFE_OFFSET_DAC, .green = AFE_OFFSET_DAC,   .blue = AFE_OFFSET_DAC, .negative = AFE_RLC_DAC_NEG}, \
                    .v_front_porch = V_FRONT_PORCH, .v_back_porch = V_BACK_PORCH, \
                    .h_front_porch = HSYNC_FRONT_PORCH, .h_back_porch = HSYNC_BACK_PORCH, \
                    .refresh_rate = REFRESH_RATE, \
                    .fine_tune = 0 \
                }, { \
                    .gain = { .red = AFE_PGA_GAIN_RGB, .green = AFE_PGA_GAIN_RGB, .blue = AFE_PGA_GAIN_RGB}, \
                    .offset = { .red = AFE_OFFSET_DAC, .green = AFE_OFFSET_DAC,   .blue = AFE_OFFSET_DAC, .negative = AFE_RLC_DAC_NEG }, \
                    .v_front_porch = V_FRONT_PORCH, .v_back_porch = V_BACK_PORCH, \
                    .h_front_porch = HSYNC_FRONT_PORCH, .h_back_porch = HSYNC_BACK_PORCH, \
                    .refresh_rate = REFRESH_RATE, \
                    .fine_tune = 0 \
                }, { \
                    .gain = { .red = AFE_PGA_GAIN_RGB, .green = AFE_PGA_GAIN_RGB, .blue = AFE_PGA_GAIN_RGB}, \
                    .offset = { .red = AFE_OFFSET_DAC, .green = AFE_OFFSET_DAC,   .blue = AFE_OFFSET_DAC, .negative = AFE_RLC_DAC_NEG}, \
                    .v_front_porch = V_FRONT_PORCH, .v_back_porch = V_BACK_PORCH, \
                    .h_front_porch = HSYNC_FRONT_PORCH, .h_back_porch = HSYNC_BACK_PORCH, \
                    .refresh_rate = REFRESH_RATE, \
                    .fine_tune = 0 \
                }, { \
                    .gain = { .red = AFE_PGA_GAIN_RGB_SOG, .green = AFE_PGA_GAIN_RGB_SOG, .blue = AFE_PGA_GAIN_RGB_SOG}, \
                    .offset = { .red = AFE_OFFSET_DAC_SOG_RED, .green = AFE_OFFSET_DAC_SOG_GREEN, .blue = AFE_OFFSET_DAC_SOG_BLUE, .negative = AFE_RLC_DAC_NEG}, \
                    .v_front_porch = V_FRONT_PORCH, .v_back_porch = V_BACK_PORCH, \
                    .h_front_porch = HSYNC_FRONT_PORCH, .h_back_porch = HSYNC_BACK_PORCH, \
                    .refresh_rate = REFRESH_RATE, \
                    .fine_tune = 0 \
                } \
            }, \
            .eof_canary = 0 \
        }
    #endif
#endif

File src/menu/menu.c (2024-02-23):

#include "menu.h"
#include "graphics.h"
#include "videoAdjust.h"
#include "overlay.h"
#include "rgbScan.h"
#include "menuGlobals.h"
#include "menuCallback.h"
#include "commands.h"
#include "wm8213Afe.h"
#include "dvi.h"

//System configuration includes
#include "common_configs.h"
#include "pico/stdlib.h"

// --------- KEYBOARD API CALL START --------- 
void menu_on_keyboard_event(keyboard_status_t keys) {
    for (uint8_t cnt = 0; cnt < menu_tot_events; cnt++) {
        menu_event_t *event = &menu_events[cnt];
        event->key_up   = keyboard_get_key_status(&keys, true, cnt); 
        event->key_down = keyboard_get_key_status(&keys, false, cnt);
        rgbScannerWake();
        switch (event->type) {
            case menu_event_action:
                if (event->key_up) {
                    if (!is_video_overlay_enabled()) {
                        // Enable Overlay, Render and Focus first element
                        video_overlay_enable(true);
                        gui_obj_draw(menu_window);
                        gui_enable(&menu_left_buttons_group);
                        gui_unfocused(menu_focused_object);
                        menu_focused_object = gui_focused(&menu_left_buttons_group_elements[0]);
                    } else if (menu_focused_object != NULL) {
                        gui_object_t *old_focus = menu_focused_object;
                        gui_object_t *new_focus = gui_deactivate(menu_focused_object);
                        if (menu_focused_object != old_focus && new_focus == old_focus) {
                            //Fix corner cases when focused object changes outside the event system
                            new_focus->base.status.focused = false;
                        }

                    }
                } else if (event->key_down && is_video_overlay_enabled() && menu_focused_object != NULL) {
                    menu_focused_object = gui_activate(menu_focused_object);
                }
                break;
            case menu_event_next:
                if (!is_video_overlay_enabled() || menu_focused_object == NULL) {
                    continue;
                }
                if (event->key_up) {
                    if (!menu_focused_object->base.status.navigable) {
                        gui_clear_add(menu_focused_object);
                    }
                } else if (event->key_down) {
                    if (menu_focused_object->base.status.navigable) {
                        menu_focused_object = gui_next_focus(menu_focused_object);
                    } else {
                        gui_set_add(menu_focused_object);
                    }
                }
                break;
            case menu_event_previous:
                if (!is_video_overlay_enabled() || menu_focused_object == NULL) {
                    continue;
                }
                if (event->key_up) {
                    if (!menu_focused_object->base.status.navigable) {
                        gui_clear_sub(menu_focused_object);
                    }
                } else if (event->key_down) {
                    if (menu_focused_object->base.status.navigable) {
                        menu_focused_object = gui_previous_focus(menu_focused_object);
                    } else {
                        gui_set_sub(menu_focused_object);
                    }
                }
                break;
            default:
                break;
        }
    }
}
// ---------  KEYBOARD API CALL END  ---------

// ---------- TIMER  CALLBACK START ----------
bool menu_update_timer_callback(struct repeating_timer *t) {
    gui_object_t *label = (gui_object_t *) t->user_data;
    if (label != NULL) {
        gui_ref_draw(label);
    }
    
    return true;
}

void menu_video_signal_callback(rgbscan_signal_event_type type) {
    bool auto_shut_down = settings_get()->flags.auto_shut_down;
    if (type == rgbscan_signal_stopped) {
        fill_rect(&menu_graphic_ctx, 0, 0, menu_graphic_ctx.width, menu_graphic_ctx.height, color_black);
        draw_textf(&menu_graphic_ctx, menu_graphic_ctx.width / 2 - 36, menu_graphic_ctx.height / 2 - 4, color_white, color_white, false, "NO SIGNAL");
        if (is_video_overlay_enabled()) {
            gui_obj_draw(menu_window);
            gui_obj_draw(menu_left_buttons_group);
            if (menu_main_view_group.base.status.visible) {
                gui_obj_draw(menu_main_view_group);
            }
        }
    } else if (type == rgbscan_signal_shutdown && auto_shut_down) {
        dvi_stop(&dvi0);
    } else if (type == rgbscan_signal_started) {
        dvi_start(&dvi0);
    }
}
// ----------- TIMER CALLBACK  END -----------

bool menu_change_view(gui_status_t status, gui_base_t *origin, menu_button_group_type new_type){
    if (!status.activated && origin->status.activated) {
        menu_left_buttons_group = menu_create_left_button_group(menu_nav_stack[menu_button_index - 1], new_type);
        gui_obj_draw(menu_window);
        gui_obj_draw(menu_left_buttons_group);
        if (menu_main_view_group.base.status.visible) {
            gui_obj_draw(menu_main_view_group);
        }
        menu_focused_object = gui_focused(&menu_left_buttons_group_elements[0]);
        
        //Once we consume this event, we dispose it due to new changes
        return false;
    }
    return true;
}

// ---------  MENU BASED GUI EVENT SLOTS HANDLERS START  ---------
bool on_display_button_event(gui_status_t status, gui_base_t *origin, gui_object_t *destination) {
    return menu_change_view(status, origin, menu_button_main_group_display);
}

bool on_configuration_button_event(gui_status_t status, gui_base_t *origin, gui_object_t *destination) {
    return menu_change_view(status, origin, menu_button_main_group_config);
}

bool on_palette_button_event(gui_status_t status, gui_base_t *origin, gui_object_t *destination) {
    return menu_change_view(status, origin, menu_button_sub_group_palette);
}

bool on_about_button_event(gui_status_t status, gui_base_t *origin, gui_object_t *destination) {
    return menu_change_view(status, origin, menu_button_sub_group_about);
}

bool on_alignment_button_event(gui_status_t status, gui_base_t *origin, gui_object_t *destination) {
    return menu_change_view(status, origin, menu_button_sub_group_alignment);
}

bool on_diagnostic_button_event(gui_status_t status, gui_base_t *origin, gui_object_t *destination) {
    return menu_change_view(status, origin, menu_button_sub_group_diagnostic);
}

bool on_gain_offset_button_event(gui_status_t status, gui_base_t *origin, gui_object_t *destination) {
    return menu_change_view(status, origin, menu_button_sub_group_gain_offset);
}

bool on_save_reboot_button_event(gui_status_t status, gui_base_t *origin, gui_object_t *destination) {
    return menu_change_view(status, origin, menu_button_sub_group_save_reboot);
}
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

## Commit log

2022-02-01 test: using systick timer with 100 times more resolution
2022-02-02 dactest: moved unified config, added adc pio prg to rgbscan lib, added dacTest
2022-02-08 test: ramp adc tests
2022-03-22 afe: first support of SPI on AFE
2022-03-23 afe: pin reconfiguration to new hw schema
2022-04-10 pio-dma: added pio program and dma management
2022-04-14 pio-dma: moved from 32 to 16 transfer due to reverted 16words ordering, corrected sampling rate
    [wm8213Afe.c]
2022-04-15 pio-dma: data is stable in falling edge of clock
2022-04-17 pio-dma: completed succesful 565 pio capture, calibrated offset and gain
2022-04-17 pio-dma: added missing stop capture
    [afeTest.c, wm8213Afe.c, wm8213Afe.h]
2022-04-20 sync: added scan callback with vertical front and back porch, added missing GPIO input mode
    [rgbScan.c, rgbScanTest.c]
2022-04-21 integration: added 320x240 test with first try capture. Corrected methods to use in ram / in line functions
    [integrationTest.c, rgbScan.c, wm8213Afe.c]
2022-04-22 integration: adding 2nd dma to drop frontporch pixels
2022-04-22 integration: image correction, size, pos, contrast and brightness
    [common_configs.h, integrationTest.c, rgbScan.c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]
2022-04-24 app: working 640x240 capture, required flipping vsmp rsmp
    [afeTest.c, integrationTest.c, wm8213Afe.c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]
2022-04-24 app: corrected hsync irq Edge to recover time
    [rgbScan.c]
2022-04-24 dma: overrun protection
2022-04-25 tune: improved timings correction
    [integrationTest.c]
2022-04-28 HW: schematic, gerber pcb and altium project
    [RGB2HDMI.schdoc]
2022-05-04 keyboard: completed implementation with events and getter, added test. Fixed rgbscan pullup
    [common_configs.h, keyboard.c, keyboardTest.c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]
2022-05-25 board: updates due to alpha board. Added menu components
2022-05-25 fix: minor improvements on timing, tick, scan and capture
    [integrationTest.c, rgbScan.c, wm8213Afe.c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]
2022-05-26 menu: progress on menu system, fixed graphic rects
    [graphicsTest.c, menu.c, menuTest.c]
2022-05-28 IRQ fixes: dedicated gpio irq in ram and higher priority
    [graphicsTest.c, integrationTest.c, menuTest.c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]
2022-06-03 overlay-graphics: interaction. Flash vs on Ram exec fixes plus optional code
    [integrationTest.c, rgbScan.c]
2022-06-06 scanFix: video scan limit fix
    [integrationTest.c, rgbScan.c, rgbScanTest.c]
2022-06-06 console: fixed windows correction
    [integrationTest.c, rgbScan.c]
2022-06-09 capture: implemented rgb2usb capture, created a tool to transform csv to png
    [file.csv]
2022-06-16 stability: wait DVI to start prior running rgbscan
    [integrationTest.c]
2022-06-17 graphics: added word wrap and error report on afe failure
    [graphicsTest.c, integrationTest.c, menu.c]
2022-08-09 Rgb332 support (#12)
    * RGB565: full 16bits rbg565, added lsb for green
    * rgb332: adding bppx into afe and initial work into hdmi
    * 332: fix 332 mode if DVI_SYMBOLS_PER_WORD==1
    * 332: completed rgb332/rgb565 tolerant graphic test
    * 332: fixing integration test graphics
    * 332: completed afe capture / pio changes to support 332 mode
    * 332: small corrections to timing makes a great change
    * 332: push to version 0.3.0, added uf2 binary
    * 332: corrected timing for 320/640 w modes
    * 332: added release notes
    [common_configs.h, graphicsTest.c, integrationTest.c]
2022-08-10 tool:convert hexa csv into png 8 and 16 bits
    [file.csv, file_320_240_16.csv, file_640_240_8.csv]
2022-08-14 Pythonapp (#14)
    * pythonapp: progress with the gui
    * pythonapp: ui and logo plus serial integration
    * pythonapp: about button and modal -ugly
    * pythonapp:completed main buttons except capture
    * pythonapp: completed functionality
    * pythonapp: making it use threads in a careless way
    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
2022-08-27 label: dynamic label generation with printf varag support
2022-09-10 Event mgmt (#16)
    * event: props and events
    * event: subscribed between objects events
2022-09-15 Focus mgmt + event propagation + spinbox (#18)
    * focus-mgmt: managed focus for current and next items
    * focus-mgmt: completed flow for inner object behavior +bugfix cast
    * focus-mgmt: fixed drawable event post update and added spinbox
    * spinbox events: implemented spinbox events
    * event-propagation: managing events of events
    * text-align: support multiline text
    [guiTest.c]
2022-09-18 fonts: C64 font and tool to generate fonts and sprites
    [file_320_240_16.csv, file_640_240_8.csv]
2022-10-04 beta hw: udpdated schematic pcb, and timing
    [PCB_RGB2HDMI_2022-09-26.pcbdoc, PCB_RGB2HDMI_2022-10-02_beta3.pcbdoc, PickAndPlace_PCB_RGB2HDMI_2022-10-02.csv]
2022-10-04 security: fixed ui license overlay
    [integrationTest.c]
2022-10-06 Test mode: added test mode with save serial key, support storage and reboot, keyset and keyget
    [integrationTest.c]
2022-10-15 storage: fixed overrun buffer on storage and improved multicore storage condition
    [common_configs.h, integrationTest.c]
2022-11-15 Csync (#21)
    * csync: multi timer
    * csync: initial support of CSYNC, enables video for H+VSYNC and CSYNC and reports correctly Horiz and vert refresh rates
    * csync: A600 CSYNC image
    [integrationTest.c, rgbScan.c]
2022-12-21 Gui integration (#22)
    * gui-integration: wip, added menu to integration test, removing command ui
    * gui-integration: first menu button group, work with show overlay and hide
    * gui-integration: first open close menu cicle with correct focus
    * gui-integration: connected buttons and spinbox events, managed back navigation
    * gui-integration: simple group unsubscribe and group execute utility
    * gui-integration: group unsubscribe using group execute utility
    * gui-integration: group execute with abort condition callback, supporting draw group with group exec cb
    * gui-integration:Single handler for spinbox
    * gui-integration: fix for focus change outside the event system
    *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
    [common_configs.h, graphicsTest.c]
2023-02-27 windows app: added instructions, fix for pyinstaller build for windows
    [csv2png.py, rgb2hdmiGui.py, serialCmd.py]
2023-03-22 capture improvement: a somehow visible mistake fix,trigger fast front porch dma, then prepare capture dma, plus no need to purge fifo for front porch
    [wm8213Afe.c, wm8213Afe.h]
2023-03-22 wake: any button will give extra time when there is no signal, on shutdown, wakes screen
2023-04-12 capture: Fix for capture changes (like pixel width) that affected the pio and made it stall
    [wm8213Afe.c]
2023-04-15 Settings storage and retrieval from flash, integrated to GUI (#26)
    * settings: initial stage of creating a settings that can be stored, reverted to factory and updated
    * settings: integration test uses settings and commands removes storage dependency
    * settings: fixed test commands that updates storage, plus security data type
    * settings: added menu colors to settings plus connecting save settings and factory reset
    * settings: fix for gain and offset sleep, completed factory settings and initialize from old versions
    * settings: managing settings for 4 displays for gain, offset, vert and horizontal porch
    * settings: included auto shut down in settings mgmt
    * settings: mov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
    [common_configs.h, integrationTest.c, menu.c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]
2023-04-21 0.5.x fixes to tests
    [graphicsTest.c, guiTest.c]
2023-04-23 gain-fix: fixed 6 bit gain error
    [common_configs.h, integrationTest.c, menu.c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]
2023-04-27 Unified color mode: on runtime HDMI mode for symbols_per_word (#27)
    * unified_color_mode: removed DVI_SYMBOLS_PER_WORD and managed as a config option
    * unified_color_mode: removed deprecated main app and capture test, unified timing for 2 modes
    * unified_color_mode: updated menu colors to manage on boot color selection
    * unified_color_mode: updated testt with 16/8 buffers
    * unified_color_mode: huge speed improvement when caching one time calculation for critical sections
    * unified_color_mode: fixed capture config without committing
    * unified_color_mode: symbols_per_word specific callbacks for video
    * unified_color_mode: starting to remove duplicated configs
    * unified_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
    [afeTest.c, common_configs.h, dvi.c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]
2023-04-28 fine_tune: Fix for unique horizontal timing, Added fine tune for pixel width (#29)
    * fine_tune: fix horizontal timing use and storage for both display modes
    * fine_tune: Fix for unique horizontal timing, Added fine tune for pixel width
    [common_configs.h, integrationTest.c, menu.c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]
2023-07-27 CIbuild: Fixed integration test compilation/linker dependency to timer plus adding build artifacts
    [rgbScan.c, wm8213Afe.c]
2024-02-23 Gain offset options (#40)
    * gain_offset_options: adding negative offset to settings mgmt
    * gain_offset_selection: changed globals for gain offset and temporarily removed gui for gain offset
    * gain_offset: building up menu
    * gain_offset: multi option gain offset menu
    * gain_offset: fixes for new compiler
    * gain_offset: adding retrieving current value to sliders
    * gain_offset: fixe for neg offset mask and update sliders
    * gain_offset: event handler of rgb and unified spinbox
    * gain_offset_options: propagate action to slider option in gain offset
    ---------
    [common_configs.h, integrationTest.c, menu.c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]
